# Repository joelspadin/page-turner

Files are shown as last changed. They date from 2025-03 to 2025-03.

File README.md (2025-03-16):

# Page Turner

This is an STM32-based "keyboard" which maps a pair of foot pedals with 6.35 mm (1/4") phone jacks to left/right arrow keys (or any other two keys), designed for switching pages on a sheet music reader. It was designed to be as small as possible while still being hand-solderable.

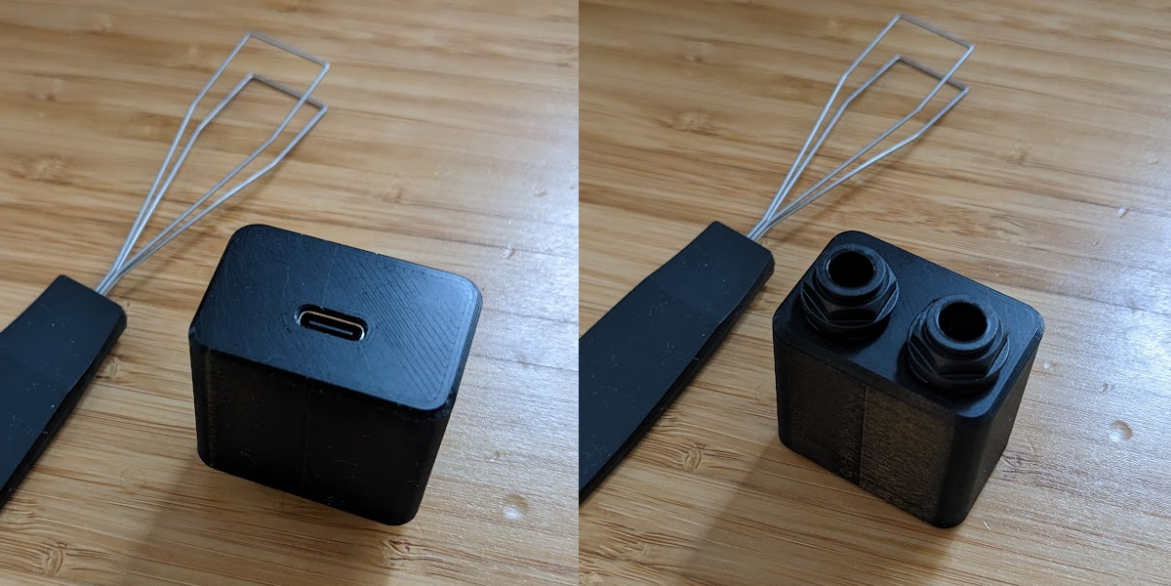
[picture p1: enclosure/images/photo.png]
Photograph of front and back sides; keycap puller for scale


# PCB

The [pcb](./pcb) folder contains a [KiCad](https://www.kicad.org/) project for the PCB. It requires 4 layers and a 1.6 mm thick PCB.

All parts are hand-solderable. I recommend starting from the USB port and working out from the center on the top side, then soldering the phone jacks last.

With [Python](https://www.python.org/) and [Docker](https://www.docker.com/products/docker-desktop/) installed, you can use [KiBot](https://github.com/INTI-CMNB/KiBot) to generate Gerber files for JLC PCB or PCBWay. Simply run the [kibot.py](./kibot.py) script, then check the "out" folder for the results.

## Bill of Materials

| References | Part | Manufacturer | Package  | Qty. | Description |
| --- | --- | --- | --- | ---- | --- |
| C5 | 10n capacitor | | 0603 | 1 | SMT Ceramic capacitor |
| C3, C7 | 100n capacitor | | 0603 | 2 | SMT Ceramic capacitor |
| C1, C2, C6 | 1u capacitor | | 0603 | 3 | SMT Ceramic capacitor |
| C4 | 4.7u capacitor | | 0603 | 1 | SMT Ceramic capacitor |
| R1, R2 | 5.1k resistor | | 0603 | 2 | SMT resistor |
| R3 | 10k resistor | | 0603 | 1 | SMT resistor |
| D1, D2 | SD03C-7 | Diodes Inc. | SOD-323  | 2 | TVS diode |
| D3 | PRTR5V0U2X,215 | Nexperia | SOT-143  | 1 | TVS diode |
| U1 | STM32F042F6P6TR | STMicroelectronics | TSSOP-20 | 1 | ARM microcontroller |
| U2 | TPS7A0533PDBVR | Texas Instruments  | SOT-23-5 | 1 | 3.3V regulator |
| SW1, SW2 | B3U-1000P-B | Omron | | 2 | Tactile switch |
| J1, J2 | NJ2FD-V | Neutrik | | 2 | 6.35 mm phone jack |
| J3 | USB4145-03-0170-C | GCT | | 1 | USB-C connector |

D1, D2, and D3 are optional. They provide some ESD protection.

U2 may be substituted with any other 3.3V regulator that takes 5V input and uses the same footprint and pinout, e.g. TPS7A0333PDBVR.

# Firmware

The [src](./src) folder contains an Arduino sketch. It can be modified as necessary to change the two keys or if your foot pedals are normally closed instead of normally open.

You will need a SWD programmer such as a J-Link. I used a [Nordic nRF5340 DK](https://www.nordicsemi.com/Products/Development-hardware/nRF5340-DK). Other programmers such as a Black Magic Probe or STLink may work, but I have not tested these. Flashing instructions below assume using a J-Link.

There are pads for a Tag-Connect TC2030 "no legs" cable, or you can use the five pads at the top of the PCB to connect your programmer (note that these have 2 mm spacing instead of 2.54 mm due to size constraints).

To compile and flash the firmware:

1. Install [STM32CubeProgrammer](https://www.st.com/en/development-tools/stm32cubeprog.html)
2. Install and open [Arduino IDE](https://www.arduino.cc/en/software)
3. Install the [Arduino core for STM32](https://github.com/stm32duino/Arduino_Core_STM32/wiki/Getting-Started)
4. Open [src/page_turner.ino](./src/page_turner.ino) in Arduino IDE
5. Select **Tools > Board > STM32 MCU based boards > Generic STM32F0 series**
6. Select **Tools > Board part number > Generif F042F6Px**
7. Select **Tools > USB support (if available) > HID (keyboard and mouse)**
8. Select **Tools > Upload method > STM32CubeProgrammer (J-Link)**
9. Plug the PCB to USB power and connect your programmer to it.
10. Select **Sketch > Upload Using Programmer**

I ran into an issue where, after being flashed with Arduino firmware, STM32CubeProgrammer was unable to identify the board afterwards. To fix this, you can run STM32CubeProgrammer and try to connect. This will fail and ask you to select the type of processor. Select Cortex M0 to finish connecting. Run a full chip erase, then disconnect, and you will be able to flash again.

## Enclosure

The [enclosure](./enclosure) folder contains CAD files that can be used to create a 3D printed enclosure.

## Bill of Materials

| Part | Qty. |
| --- | ---- |
| [Back](./enclosure/Back.3mf) (3D printed) | 1 |
| [Front](./enclosure/Front.3mf) (3D printed) | 1 |
| M2 x 3 mm heat-set insert | 4 |
| M2 x 5 mm counersunk screw | 4 |

## Assembly

1. Using a soldering iron, install the four heat set inserts into the holes in the back piece.

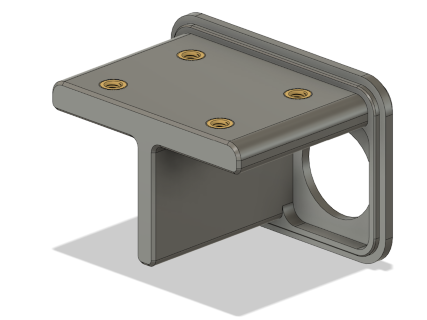
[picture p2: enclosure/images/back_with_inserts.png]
Back piece with heat-set inserts
   

2. Place the PCB assembly into the back piece. The longer side of the PCB should line up with side of the back piece containing the heat-set inserts.

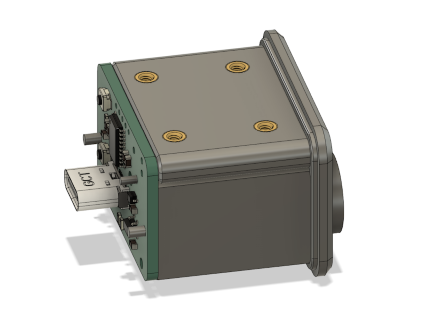
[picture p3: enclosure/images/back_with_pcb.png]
Back piece with PCB
   

3. Press the caps into the 6.35 mm phone jacks and rotate them clockwise to lock them into place.
4. Slide the front piece on, lining up the four holes with the heat set inserts.

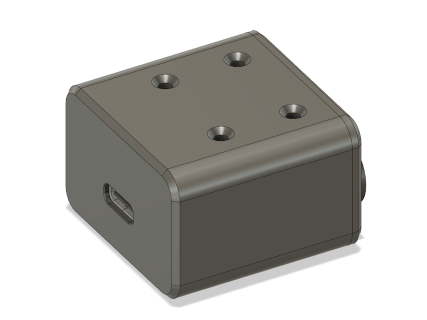
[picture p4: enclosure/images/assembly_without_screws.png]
Front and back piece assembly, without screws
   

5. Install the four screws.

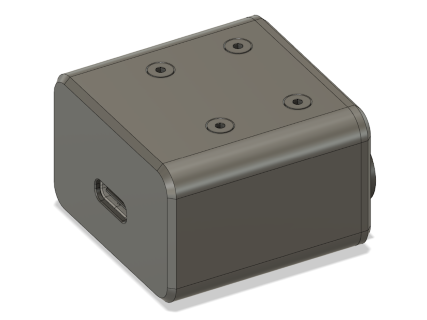
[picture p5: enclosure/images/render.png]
Finished assembly


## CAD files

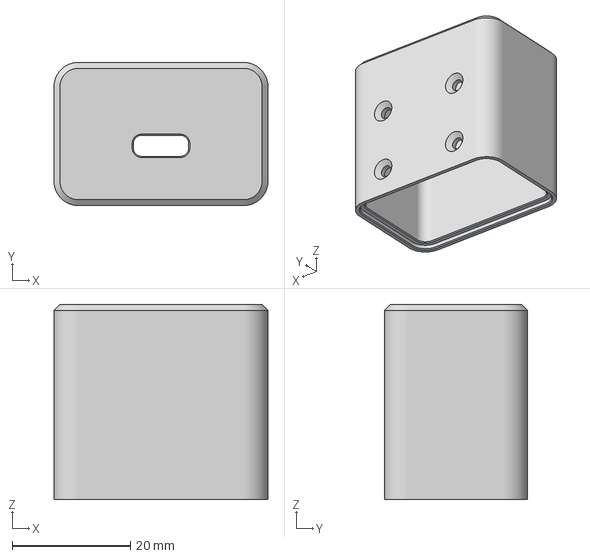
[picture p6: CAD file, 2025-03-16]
enclosure/Front.3mf
36.2 x 24.2 x 33.0 mm

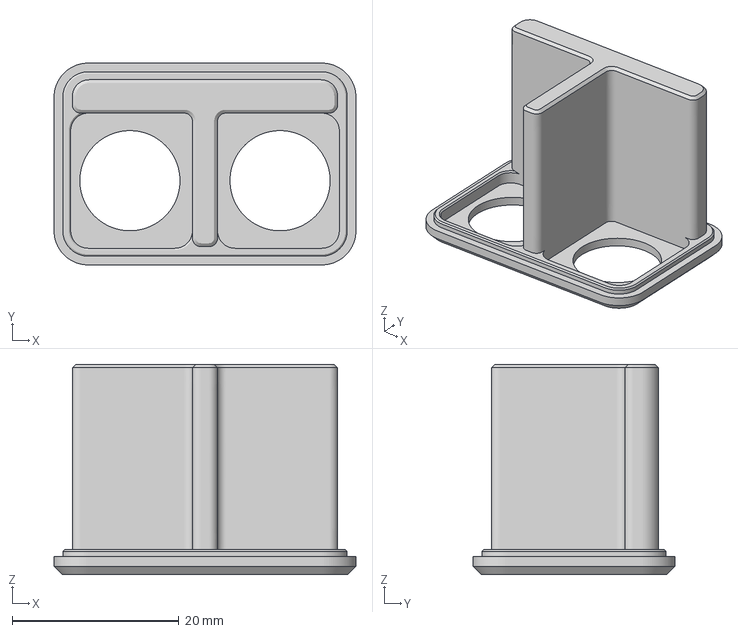
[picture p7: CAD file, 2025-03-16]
enclosure/Back.3mf
36.2 x 24.2 x 25.2 mm

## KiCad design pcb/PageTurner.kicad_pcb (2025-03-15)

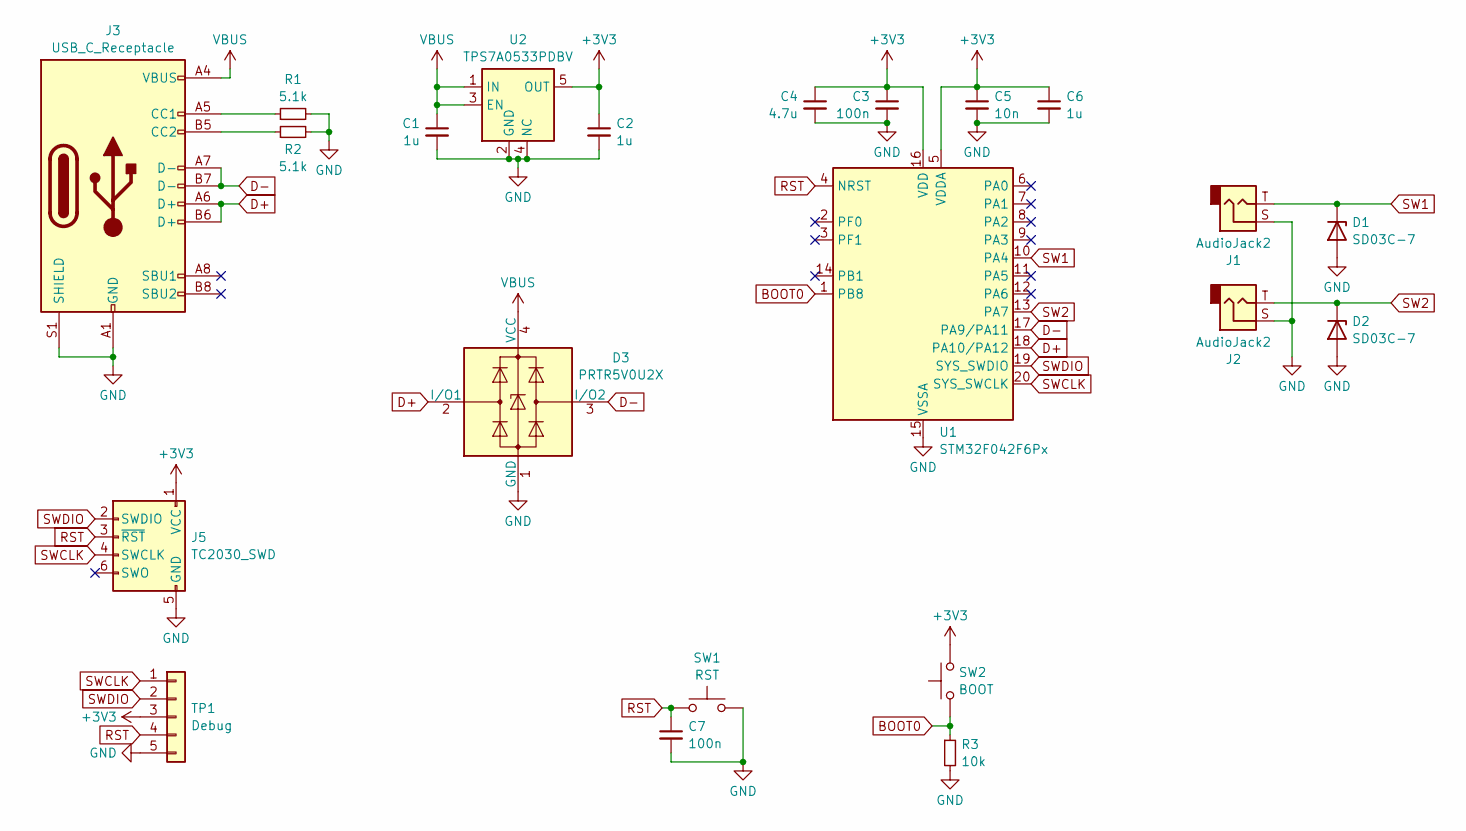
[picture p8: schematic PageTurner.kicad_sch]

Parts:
C1, C2, C6: 1u; C_0603_1608Metric_Pad1.08x0.95mm_HandSolder
C3, C7: 100n; C_0603_1608Metric_Pad1.08x0.95mm_HandSolder
C4: 4.7u; C_0603_1608Metric_Pad1.08x0.95mm_HandSolder
C5: 10n; C_0603_1608Metric_Pad1.08x0.95mm_HandSolder
D1, D2: SD03C-7; D_SOD-323_HandSoldering; Manufacturer Part Number SD03C-7
D3: PRTR5V0U2X; SOT-143; Manufacturer Part Number PRTR5V0U2X,215
J1, J2: AudioJack2; Jack_6.35mm_Neutrik_NJ2FD-V_Vertical; Manufacturer Part Number NJ2FD-V
J3: USB_C_Receptacle; USB_C_Receptacle_GCT_USB_4145; Manufacturer Part Number DX07S024WJ3R400
J5: TC2030_SWD; Tag-Connect_TC2030-IDC-NL_2x03_P1.27mm_Vertical
R1, R2: 5.1k; R_0603_1608Metric_Pad0.98x0.95mm_HandSolder
R3: 10k; R_0603_1608Metric_Pad0.98x0.95mm_HandSolder
SW1: RST; SW_SPST_B3U-1000P-B; Manufacturer Part Number B3U-1100P-B
SW2: BOOT; SW_SPST_B3U-1000P-B; Manufacturer Part Number B3U-1100P-B
TP1: Debug; PinHeader_1x05_P2.00mm_Vertical
U1: STM32F042F6Px; TSSOP-20_4.4x6.5mm_P0.65mm; Manufacturer Part Number STM32F042F6P6TR
U2: TPS7A0533PDBV; SOT-23-5; Manufacturer Part Number TPS7A0333PDBVR

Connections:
+3V3: C2.1, C3.1, C4.1, C5.1, C6.1, J5.1 (VCC), SW2.2, TP1.3, U1.5 (VDDA), U1.16 (VDD), U2.5 (OUT)
BOOT0: R3.1, SW2.1, U1.1 (PB8)
D+: D3.2 (I/O1), J3.A6 (D+), J3.B6 (D+), U1.18 (PA10/PA12)
D-: D3.3 (I/O2), J3.A7 (D-), J3.B7 (D-), U1.17 (PA9/PA11)
GND: C1.2, C2.2, C3.2, C4.2, C5.2, C6.2, C7.2, D1.2 (A), D2.2 (A), D3.1 (GND), J1.S, J2.S, J3.A1 (GND), J3.A12 (GND), J3.B1 (GND), J3.B12 (GND), J3.S1 (SHIELD), J5.5 (GND), R1.2, R2.2, R3.2, SW1.2, TP1.5, U1.15 (VSSA), U2.2 (GND), U2.4 (NC)
unnamed: J3.A5 (CC1), R1.1
unnamed: J3.B5 (CC2), R2.1
RST: C7.1, J5.3 (~RST), SW1.1, TP1.4, U1.4 (NRST)
SW1: D1.1 (K), J1.T, U1.10 (PA4)
SW2: D2.1 (K), J2.T, U1.13 (PA7)
SWCLK: J5.4 (SWCLK), TP1.1, U1.20 (SYS_SWCLK)
SWDIO: J5.2 (SWDIO), TP1.2, U1.19 (SYS_SWDIO)
VBUS: C1.1, D3.4 (VCC), J3.A4 (VBUS), J3.A9 (VBUS), J3.B4 (VBUS), J3.B9 (VBUS), U2.1 (IN), U2.3 (EN)

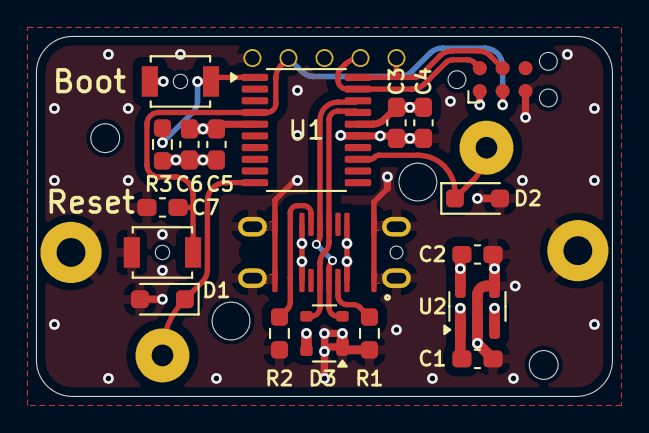
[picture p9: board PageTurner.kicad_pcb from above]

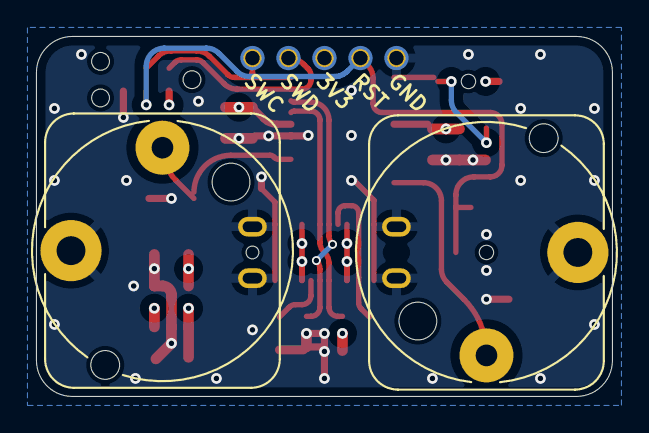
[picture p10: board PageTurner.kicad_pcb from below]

Board: 4 copper layers, 32.0 x 20.0 mm, 22 parts (3 on the bottom side), 13 nets.

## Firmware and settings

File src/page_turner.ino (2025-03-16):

// Copyright (c) 2025 Joel Spadin
// SPDX-License-Identifier: MIT

#include <Keyboard.h>

// Target scan rate
const unsigned long MicrosPerLoop = 1000;

// Key must be pressed/released for this number of milliseconds to register.
const int DebouncePressMillis = 1;
const int DebounceReleaseMillis = 5;

// Number of scan cycles for debounce press/release
const int DebouncePressCount = DebouncePressMillis * 1000 / MicrosPerLoop;
const int DebounceReleaseCount = DebounceReleaseMillis * 1000 / MicrosPerLoop;

const uint16_t DebounceCounterMax = 0b0111111111111111;

struct KeyState {
  bool pressed : 1;
  uint16_t counter : 15;
};

struct Key {
  uint32_t pin;
  int activeValue;
  uint8_t key;
  struct KeyState state;
};

// Keymap
// Change LOW to HIGH if your pedals are normally closed swithces.
struct Key keys[] = {
  {PA7, LOW, KEY_LEFT_ARROW},
  {PA4, LOW, KEY_RIGHT_ARROW},
};

// Get the number of consecutive scan cycles needed to change states
uint16_t getDebounceThreshold(const struct KeyState& state) {
  return state.pressed ? DebounceReleaseCount : DebouncePressCount;
}

void decrementCounter(struct KeyState& state) {
  if (state.counter > 0) {
    state.counter--;
  }
}

void incrementCounter(struct KeyState& state) {
  if (state.counter < DebounceCounterMax) {
    state.counter++;
  }
}

// Debounce using a variant of the algorithm described at
// https://www.kennethkuhn.com/electronics/debounce.c
// Returns true if the state changed.
bool debounce(struct KeyState& state, bool pressed) {
  if (pressed == state.pressed) {
    decrementCounter(state);
    return false;
  }

  const auto flipThreshold = getDebounceThreshold(state);

  if (state.counter < flipThreshold) {
    incrementCounter(state);
    return false;
  }


  state.pressed = !state.pressed;
  state.counter = 0;

  return true;
}

unsigned long nextLoopTime;

void setup() {
  for (const auto& key : keys) {
    pinMode(key.pin, INPUT_PULLUP);
  }

  Keyboard.begin();

  nextLoopTime = micros() + MicrosPerLoop;
}

void loop() {
  for (auto& key : keys) {
    const auto pressed = digitalRead(key.pin) == key.activeValue;
    const auto changed = debounce(key.state, pressed);

    if (changed) {
      if (key.state.pressed) {
        Keyboard.press(key.key);
      } else {
        Keyboard.release(key.key);
      }
    }
  }

  nextLoopTime += MicrosPerLoop;
  const auto now = micros();
  if (now < nextLoopTime) {
    delayMicroseconds(nextLoopTime - now);
  }
}

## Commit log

2024-12-15 Increase spacing between jacks slightly
    [PageTurner.kicad_pcb]
2024-12-18 Update bom, fix decoupling capacitor value
    [PageTurner.kicad_pcb, PageTurner.kicad_sch]
2024-12-19 Add ESD diodes for pedal inputs
    [PageTurner.kicad_pcb, PageTurner.kicad_sch]
2024-12-19 Use cheaper ESD diode
    [PageTurner.kicad_pcb, PageTurner.kicad_sch]
2024-12-20 Use 1.6 mm PCB
    [PageTurner.kicad_pcb]
2024-12-20 Switch to a cheaper and smaller USB connector
    [PageTurner.kicad_pcb, PageTurner.kicad_sch]
2025-01-02 Switch to 4 layers, add USB ESD diode
    [PageTurner.kicad_pcb, PageTurner.kicad_sch]
2025-01-02 Move USB ESD to top
    [PageTurner.kicad_pcb]
2025-01-05 General cleanup
    [PageTurner.kicad_pcb, PageTurner.kicad_sch]
2025-03-15 Disconnect GPIOs from GND
    GPIOs are supposed to power up in floating input mode, so I tied some of
    them to GND for easier routing. For some reason the input voltage sagged
    to ~0.6 V until I disconnected these pins from the PCB though. I'm not
    sure if this was the cause or I just messed up soldering something, but
    disconnecting these just to be safe.
    [PageTurner.kicad_pcb, PageTurner.kicad_sch]
2025-03-16 Add code and 3D files, update README and LICENSE
    Added an Arduino sketch and updated the README with instructions for
    building and flashing it.
    Added 3D model files for the enclosure and updated the README with
    instructions for assembling it.
    Added a license for the Arduino sketch. Removed license information for
    footprints that were copied from another project but have been removed
    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
    [Back.3mf, Front.3mf]
2025-03-16 Fix dockerfile for KiCad 9, add instructions
